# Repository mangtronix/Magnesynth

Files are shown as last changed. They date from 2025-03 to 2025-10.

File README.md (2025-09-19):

# Magnesynth

Modular synthesizer combining physical strings, modular synthesis, physical computing, and electromagnetic phenomena

A full system is
- CB-100 Center Bridge with handle
- 2x EB-100 End Bridge
- 4x F-100 Foot
- 1x P-100 Pickup Mount
- 1x P-101 Pickup Tone Control
- 1x SH-100 Shelf (Left/Right/Middle)
- 1x TB-100 Tuner Block and nut

Rail parts
- 3x 3030 70cm - [Amazon AE](https://www.amazon.ae/dp/B0CGZVSVVL)
- 2x 3030 30cm - [Amazon AE](https://www.amazon.ae/dp/B0CGZV8VY2)
- 8x 3030 T-slot L corner bracket - [Amazon AE](https://www.amazon.ae/dp/B0CHFF6B6S)
- 1x 3030 inside corner bracket - for holding strings - [Amazon AE](https://www.amazon.ae/dp/B0BFW3GV5R)
  - Cut slots using TOOL-100 String holder cut guide
- M6 hammer bolts w/hex nut - for panels
- M5 round head bolts with M5 nut - 8mm for shelves, 12mm for tuner block - [Amazon AE](https://www.amazon.ae/dp/B0CHMN8DZ2)

Michael_Ang-Magnesynth
[Mang](https://michaelang.com) performing on the Magnesynth

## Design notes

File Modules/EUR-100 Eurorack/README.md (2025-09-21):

# EUR-100 Eurorack

EUR-100 Case Bottom

3D-printed Eurorack case with metal rails. The design is parametric for easy scaling.

The case is designed for internal brackets but could easily be adapted to use bolts that go through the sides of the case. Prints in one piece without supports. The threads for the bolts are printed into the case.

Parts:
- [TipTop Z-rails](https://tiptopaudio.com/z-rails/)
- [TipTop Z-rails brackets](https://tiptopaudio.com/z-rails-brackets/)

Example setup with instrument input, effects, and line level output.



Magnesynth v1 40hp clean

[Magnesynth v1 40hp Modulargrid Rack](https://modulargrid.net/e/racks/view/2945002)

EUR-100 Performance
Live performance in Dubai by Mang

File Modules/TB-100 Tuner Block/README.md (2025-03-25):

# TB-100 Tuner Block

**These parts needs to be strong!** The tuner block and nut hold the tension from the strings.  Use at your own risk.

I recommend printing these parts in **PETG** (ASA/ABS would also likely work).

**I do NOT recommend printing these parts in PLA**.  PLA is likely to fail catastrophically (crack) over time.  

With the Guyker tuning machines listed below the tab on the tuners keeps them from rotating against the block. Otherwise you can use the screws provided with the tuners to keep the tuners from rotating.

Recommended settings:
  - Material: PETG
  - Layers and perimeters
    - Perimeters: 7
    - Solid layers: Top: 6, Bottom: 6
  - Infill
    - Fill density: 40%
    - Fill pattern: Cubic

Parts required:
  - 4x tuning machines, e.g. [1 Set GUYKER Locking Guitar Machine Heads 6R](https://www.aliexpress.com/item/1005008338893519.html)
  - 5x M5 nut
  - 5x M5 round head bolt 12mm

Dimensions of Guyker locking tuner used in reference design
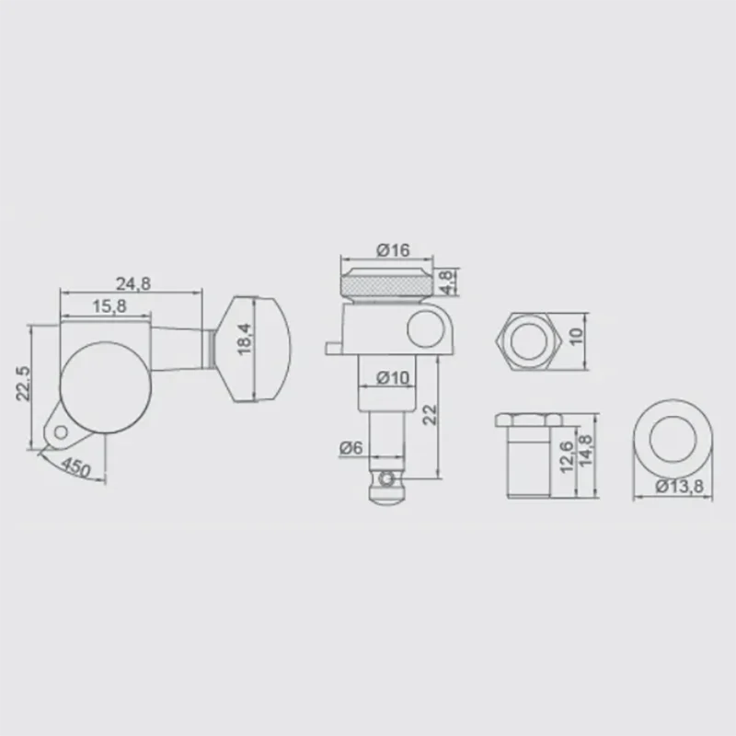
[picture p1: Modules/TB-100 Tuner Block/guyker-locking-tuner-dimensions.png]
Dimensions of Guyker locking tuner


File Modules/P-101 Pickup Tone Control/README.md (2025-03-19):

# P-101 Pickup Tone Control

Parts required
- 250k audio taper potentiometer - Volume control
- 500k audio taper potentiometer - Tone control
- 0.047uF capacitor - Tone control
- 1/4" mono audio jack

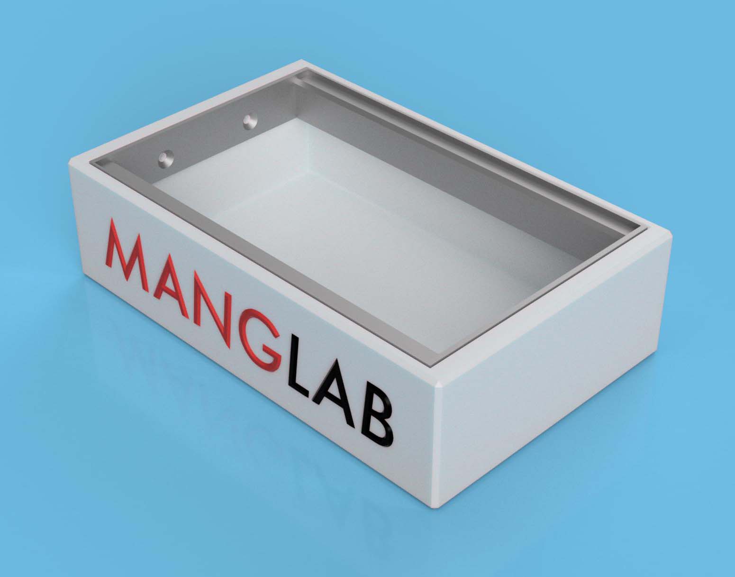
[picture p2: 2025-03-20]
Modules/EUR-100 Eurorack/EUR-100 Case Bottom.jpg

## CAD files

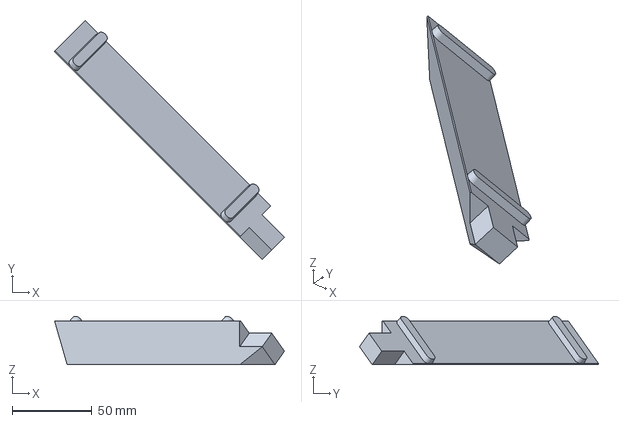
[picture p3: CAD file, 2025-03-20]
Modules/CB-100 Center Bridge with handle/CB-100 CenterBridge-handle-MK4.3mf
144.6 x 150.3 x 30.4 mm

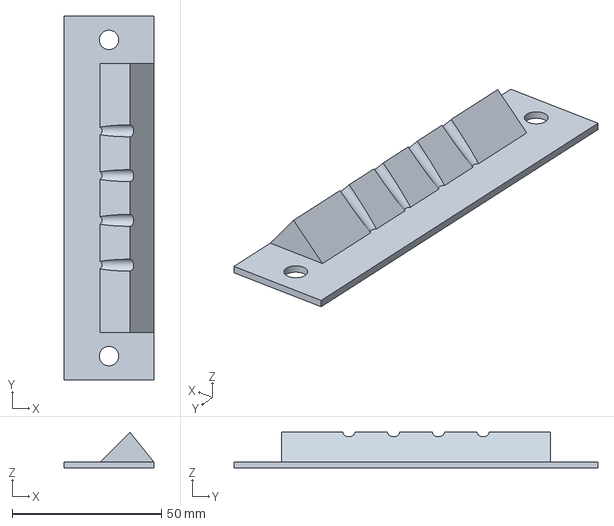
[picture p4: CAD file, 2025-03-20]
Modules/EB-100 End Bridge/B-100 End Bridge - 4mm slots-MK4.3mf
30.0 x 122.0 x 12.0 mm

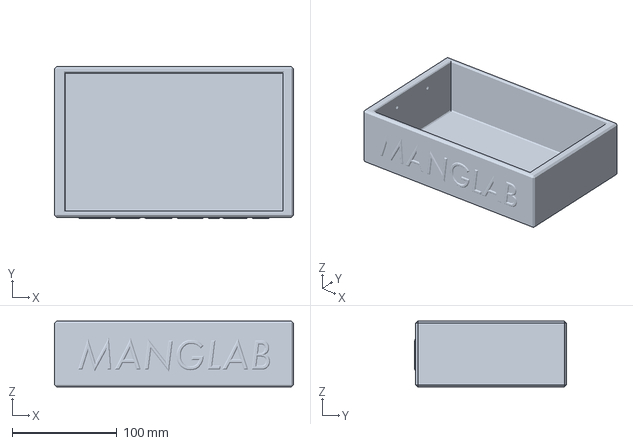
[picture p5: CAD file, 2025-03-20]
Modules/EUR-100 Eurorack/EUR-100 CaseBottom - XL-3T.3mf
228.3 x 145.0 x 63.0 mm

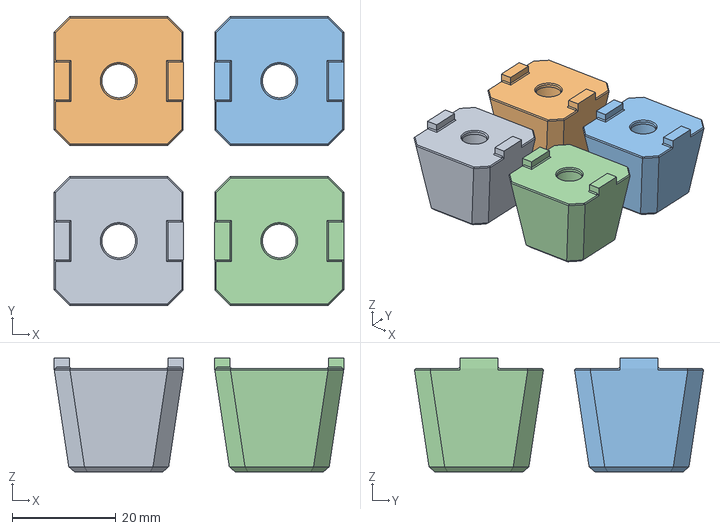
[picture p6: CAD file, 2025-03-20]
Modules/F-100 Foot/F-100 Foot_x4-MK4.3mf
56.0 x 55.8 x 22.0 mm

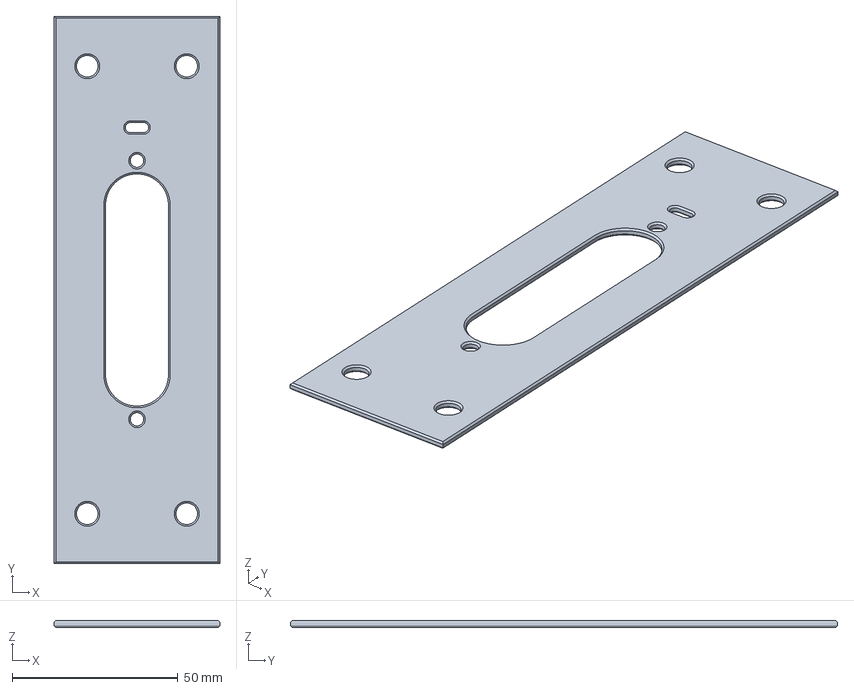
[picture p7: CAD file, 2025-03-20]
Modules/P-100 Pickup Mount/P-100 Pickup Mount-MK4.3mf
50.0 x 165.0 x 2.00 mm

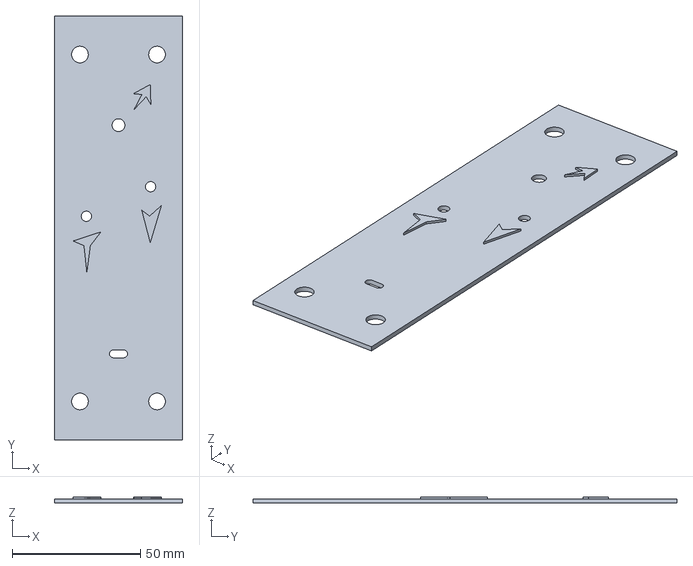
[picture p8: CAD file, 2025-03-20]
Modules/P-101 Pickup Tone Control/P-101 Pickup Tone Control-MK4.3mf
50.0 x 165.0 x 2.40 mm

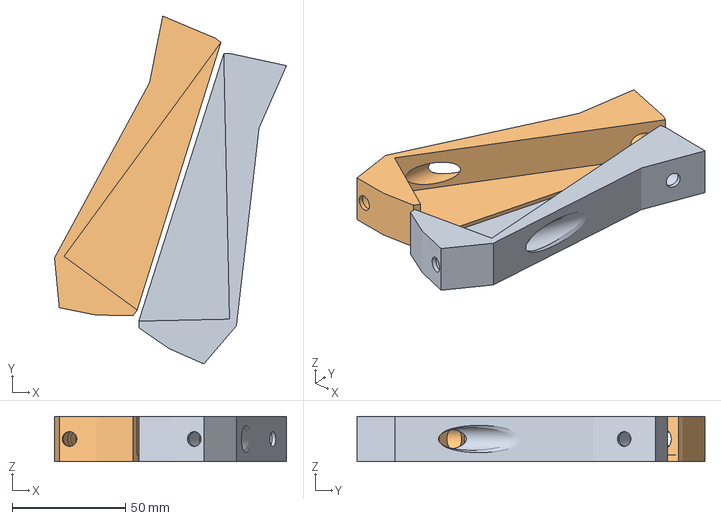
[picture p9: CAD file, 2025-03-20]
Modules/SH-100 Shelf/SH-100 Shelf LR-MK4.3mf
102.3 x 153.3 x 20.0 mm
ShelfL.stl
ShelfR.stl

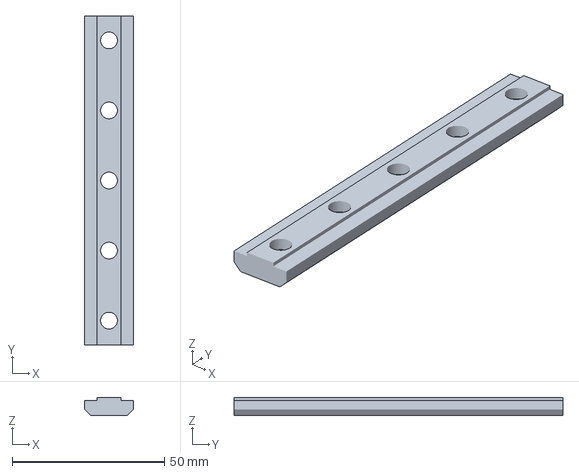
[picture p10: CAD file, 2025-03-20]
Modules/TB-100 Tuner Block/TB-100 Tuner BlockNut-MK4.3mf
16.0 x 108.0 x 6.00 mm

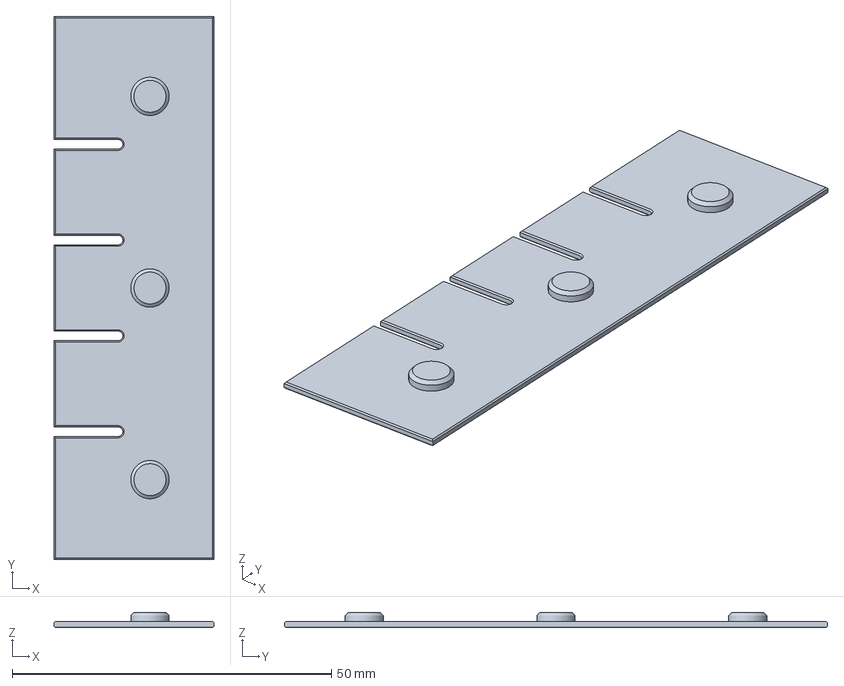
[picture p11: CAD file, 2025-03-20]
Modules/TOOL-100 String holder cut guide/TOOL-100 String holder cut guide-MK4.3mf
25.0 x 85.0 x 2.40 mm

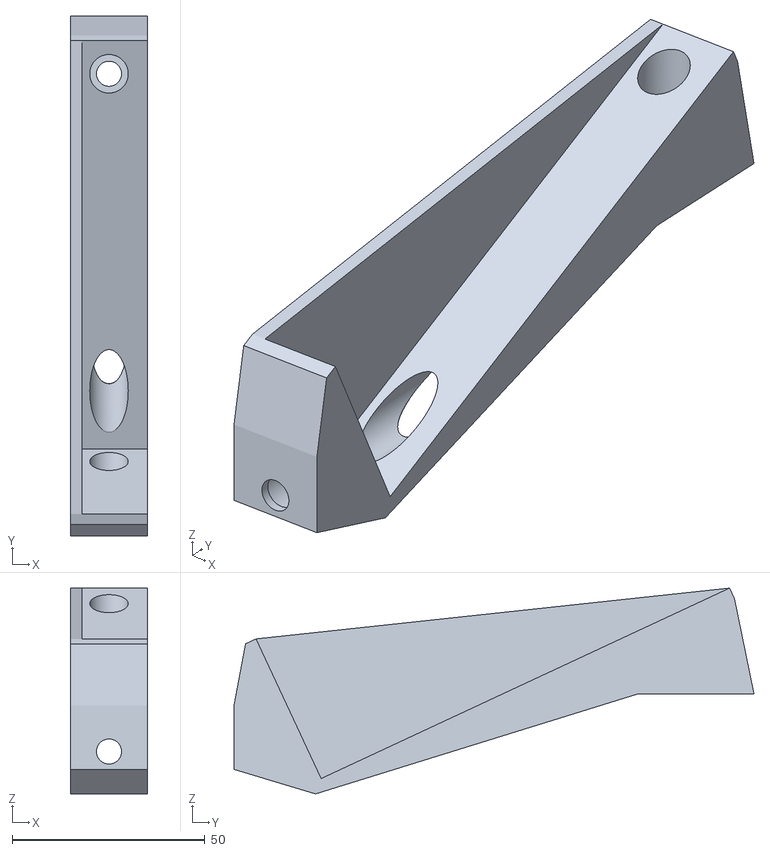
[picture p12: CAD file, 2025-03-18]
Versions/v89/String Thing v89_String Thing v89_ShelfL_1_ShelfL.stl
20.0 x 135.0 x 53.4

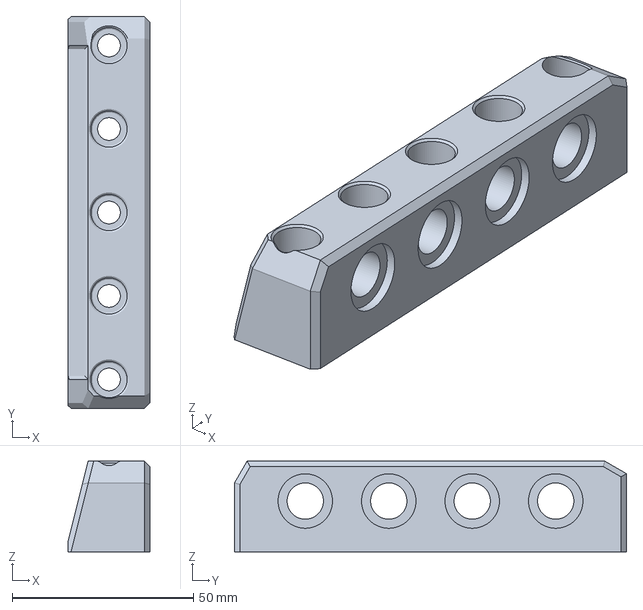
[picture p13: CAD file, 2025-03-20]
Modules/TB-100 Tuner Block/TB-100 Tuner Block-MK4.3mf
22.5 x 108.0 x 25.0 mm

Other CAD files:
Modules/CB-100 Center Bridge with handle/CB-100 CenterBridge-handle-Mini.3mf
Modules/EB-100 End Bridge/B-100 End Bridge - 4mm slots-MK3S.3mf
Modules/F-100 Foot/F-100 Foot_x4-Mini.3mf
Modules/P-100 Pickup Mount/P-100 Pickup Mount-MK3.3mf
Modules/P-101 Pickup Tone Control/P-101 Pickup Tone Control-MK3S.3mf
Modules/SH-100 Shelf/SH-100 Shelf LR-MK3S.3mf
Modules/TOOL-100 String holder cut guide/TOOL-100 String holder cut guide-MK3S.3mf
Modules/CB-100 Center Bridge with handle/CB-100 CenterBridge with handle.stl
Modules/EB-100 End Bridge/B-100 End Bridge - 4mm slots.stl
Modules/EUR-100 Eurorack/EUR-100 Eurorack.f3d
Modules/F-100 Foot/F-100 Foot.stl
Modules/P-100 Pickup Mount/P-100 Pickup Mount.stl
Modules/P-101 Pickup Tone Control/P-101 Pickup Tone Control.stl
Modules/SH-100 Shelf/SH-100-L Shelf L.stl
Modules/SH-100 Shelf/SH-100-M Shelf Middle.stl
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

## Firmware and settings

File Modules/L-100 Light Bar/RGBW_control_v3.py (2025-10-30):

# SPDX-FileCopyrightText: 2021 Kattni Rembor for Adafruit Industries
# SPDX-License-Identifier: MIT

# CREATED BY: Mustafa Bakir
#             Using Claude 4.5
# DATE      : 09/10/2025
# ---------MANGLAB----------
"""
NeoPixel RGBW Control using NeoKey and NeoSlider with Preset Storage
- Button A controls Red channel
- Button B controls Green channel
- Button C controls Blue channel
- Button D controls White/Brightness/Alpha channel
- Slider adjusts the selected channel(s) value (0-255)
- Multiple channels can be selected simultaneously
- Press a selected button again to deselect it
- Last preset is automatically saved and restored on power-up
"""

import board
import time
import neopixel as board_neopixel
from adafruit_seesaw.seesaw import Seesaw
from adafruit_seesaw.analoginput import AnalogInput
from adafruit_seesaw import neopixel
from adafruit_neokey.neokey1x4 import NeoKey1x4
import microcontroller

# flip display so buttons on right
display = board.DISPLAY
display.rotation = 180

print("NeoPixel RGBW Control Demo - Multi-Channel with Preset Storage")

# debug flags
ENABLE_DEBUG = True
SHOW_CHANNEL_CHANGES = True
SHOW_VALUE_CHANGES = True

# preset storage config
PRESET_SAVE_DELAY = 2.0  # secs before auto-save
MAGIC_BYTE = 0xA5  # magic byte for valid data
NVM_START_ADDR = 0  # start addr in nvm

# let i2c devices wake up
time.sleep(0.5)

# neopixel strip on A0 (8px)
NUM_PIXELS = 8
main_pixels = board_neopixel.NeoPixel(board.A0, NUM_PIXELS, brightness=1.0, auto_write=False, pixel_order=board_neopixel.GRBW)

# neoslider setup
i2c = board.I2C()
neoslider_address = 0x38  # A3 cut to avoid conflict w/ neokey at 0x30
print("Connecting to NeoSlider at %x" % neoslider_address)
neoslider = Seesaw(i2c, neoslider_address)
fader = AnalogInput(neoslider, 18)  # slider position
slider_pixels = neopixel.NeoPixel(neoslider, 14, 4, pixel_order=neopixel.GRB)

# neokey setup
print("Setting up NeoKey")
neokey = NeoKey1x4(i2c, addr=0x30)

# preset storage funcs
def save_preset(r, g, b, w):
    """save rgbw to nvm: [magic, r, g, b, w, checksum]"""
    try:
        # calc checksum (xor all vals)
        checksum = MAGIC_BYTE ^ r ^ g ^ b ^ w

        # prep data
        data = bytearray([MAGIC_BYTE, r, g, b, w, checksum])

        print("=== SAVING PRESET ===")
        print(f"Saving: R={r}, G={g}, B={b}, W={w}")
        print(f"Data to write: {[hex(b) for b in data]}")

        # write to nvm
        microcontroller.nvm[NVM_START_ADDR:NVM_START_ADDR + 6] = data

        # verify write
        verify = microcontroller.nvm[NVM_START_ADDR:NVM_START_ADDR + 6]
        print(f"Verification read: {[hex(b) for b in verify]}")

        if list(data) == list(verify):
            print("✓ Preset saved and verified successfully")
            print("=== END SAVE ===\n")
            return True
        else:
            print("ERROR: Write verification failed!")
            print("=== END SAVE ===\n")
            return False

    except Exception as e:
        print(f"ERROR saving preset: {e}")
        import traceback
        traceback.print_exception(e)
        return False

def load_preset():
    """load rgbw from nvm, returns (r,g,b,w) or None"""
    try:
        # read 6 bytes
        data = microcontroller.nvm[NVM_START_ADDR:NVM_START_ADDR + 6]

        # debug: show raw mem
        print("=== NVM DEBUG ===")
        print(f"Raw NVM bytes: {[hex(b) for b in data]}")
        print(f"Magic byte expected: {hex(MAGIC_BYTE)}, found: {hex(data[0])}")

        # verify magic byte
        if data[0] != MAGIC_BYTE:
            print("No valid preset found (magic byte mismatch)")
            print(f"This is likely first boot or memory was cleared")
            return None

        # extract vals
        r, g, b, w = data[1], data[2], data[3], data[4]
        stored_checksum = data[5]

        print(f"Stored values: R={r}, G={g}, B={b}, W={w}")
        print(f"Stored checksum: {hex(stored_checksum)}")

        # verify checksum
        calculated_checksum = MAGIC_BYTE ^ r ^ g ^ b ^ w
        print(f"Calculated checksum: {hex(calculated_checksum)}")

        if calculated_checksum != stored_checksum:
            print("ERROR: Preset corrupted (checksum mismatch)")
            return None

        # validate ranges (0-255)
        if not all(0 <= val <= 255 for val in [r, g, b, w]):
            print("ERROR: Preset values out of range")
            return None

        print(f"✓ Preset loaded successfully: R={r}, G={g}, B={b}, W={w}")
        print("=== END NVM DEBUG ===\n")
        return (r, g, b, w)

    except Exception as e:
        print(f"ERROR loading preset: {e}")
        import traceback
        traceback.print_exception(e)
        return None

def clear_preset():
    """clear stored preset"""
    try:
        microcontroller.nvm[NVM_START_ADDR:NVM_START_ADDR + 6] = bytearray([0] * 6)
        debug_print("Preset cleared", "general")
    except Exception as e:
        print(f"Error clearing preset: {e}")

# init rgbw - try load from storage first
stored_preset = load_preset()
if stored_preset:
    red_value, green_value, blue_value, white_value = stored_preset
    print(f"Restored preset: R={red_value}, G={green_value}, B={blue_value}, W={white_value}")
else:
    red_value = 0
    green_value = 0
    blue_value = 0
    white_value = 0
    print("Starting with default values (all zeros)")

# track selected channels [r, g, b, w]
selected_channels = [False, False, False, False]

# prev button states for edge detection
prev_button_states = [False, False, False, False]

# prev slider val for change detection
prev_slider_value = -1

# auto-save tracking
last_change_time = time.monotonic()
values_need_saving = False
last_saved_values = (red_value, green_value, blue_value, white_value)

def debug_print(message, debug_type="general"):
    """print debug msgs based on flags"""
    if not ENABLE_DEBUG:
        return

    if debug_type == "channel" and SHOW_CHANNEL_CHANGES:
        print(message)
    elif debug_type == "value" and SHOW_VALUE_CHANGES:
        print(message)
    elif debug_type == "general":
        print(message)

def map_slider_to_byte(value):
    """map slider val (0-1023) to byte (0-255)"""
    return int(value * 255 / 1023)

def update_main_pixels():
    """update all neopixels w/ current rgbw"""
    for i in range(NUM_PIXELS):
        if hasattr(main_pixels, 'fill'):
            main_pixels[i] = (red_value, green_value, blue_value, white_value)
        else:
            # rgb pixels - use white as brightness
            brightness_factor = (white_value / 255.0) if white_value > 0 else 1.0
            main_pixels[i] = (
                int(red_value * brightness_factor),
                int(green_value * brightness_factor),
                int(blue_value * brightness_factor)
            )
    main_pixels.show()

def update_slider_leds():
    """update slider leds to show channel selection"""
    num_selected = sum(selected_channels)

    if num_selected == 0:
        # no channels - dim white
        slider_pixels.fill((10, 10, 10))
    elif num_selected == 1:
        # single channel - show color
        if selected_channels[0]:  # red
            slider_pixels.fill((255, 0, 0))
        elif selected_channels[1]:  # green
            slider_pixels.fill((0, 255, 0))
        elif selected_channels[2]:  # blue
            slider_pixels.fill((0, 0, 255))
        elif selected_channels[3]:  # white
            slider_pixels.fill((255, 255, 255))
    else:
        # multi channel - show mix
        r = 255 if selected_channels[0] else 0
        g = 255 if selected_channels[1] else 0
        b = 255 if selected_channels[2] else 0
        w = 255 if selected_channels[3] else 0

        # blend white in if selected
        if selected_channels[3]:
            r = min(255, r + 128)
            g = min(255, g + 128)
            b = min(255, b + 128)

        slider_pixels.fill((r, g, b))

def get_selected_channels_string():
    """get string repr of selected channels"""
    channel_names = ["R", "G", "B", "W"]
    selected = [channel_names[i] for i, sel in enumerate(selected_channels) if sel]
    return "+".join(selected) if selected else "None"

def check_and_save_preset():
    """check if preset needs saving and save if appropriate"""
    global values_need_saving, last_saved_values

    current_values = (red_value, green_value, blue_value, white_value)

    if values_need_saving and current_values != last_saved_values:
        current_time = time.monotonic()

        # save if enough time passed since last change
        if current_time - last_change_time >= PRESET_SAVE_DELAY:
            if save_preset(red_value, green_value, blue_value, white_value):
                last_saved_values = current_values
                values_need_saving = False

# init neokey leds to show current vals
for i in range(4):
    if i == 0:
        neokey.pixels[0] = (red_value//8, 0, 0)
    elif i == 1:
        neokey.pixels[1] = (0, green_value//8, 0)
    elif i == 2:
        neokey.pixels[2] = (0, 0, blue_value//8)
    elif i == 3:
        neokey.pixels[3] = (white_value//8, white_value//8, white_value//8)

# init display w/ restored preset
update_main_pixels()
update_slider_leds()

print("Entering main loop")
print("Press buttons to select/deselect color channels")
print("Multiple channels can be selected simultaneously")
print("Move slider to adjust selected channel(s)")
print(f"Preset will auto-save after {PRESET_SAVE_DELAY}s of inactivity")

while True:
    # neokey handling - check button presses (edge detection)
    for i in range(4):
        current_state = neokey[i]

        # detect button press (rising edge)
        if current_state and not prev_button_states[i]:
            # toggle selection
            selected_channels[i] = not selected_channels[i]

            channel_names = ["Red", "Green", "Blue", "White/Brightness"]

            if selected_channels[i]:
                debug_print(f"Selected {channel_names[i]} channel", "channel")
            else:
                debug_print(f"Deselected {channel_names[i]} channel", "channel")

            debug_print(f"Active channels: {get_selected_channels_string()}", "channel")
            update_slider_leds()

        prev_button_states[i] = current_state

    # update neokey leds to show selection and vals
    for i in range(4):
        if selected_channels[i]:
            # bright color for selected
            if i == 0:
                neokey.pixels[0] = (255, 0, 0)
            elif i == 1:
                neokey.pixels[1] = (0, 255, 0)
            elif i == 2:
                neokey.pixels[2] = (0, 0, 255)
            elif i == 3:
                neokey.pixels[3] = (255, 255, 255)
        else:
            # dim indicator showing current val
            if i == 0:
                neokey.pixels[0] = (red_value//8, 0, 0)
            elif i == 1:
                neokey.pixels[1] = (0, green_value//8, 0)
            elif i == 2:
                neokey.pixels[2] = (0, 0, blue_value//8)
            elif i == 3:
                neokey.pixels[3] = (white_value//8, white_value//8, white_value//8)

    # neoslider handling - adjust selected channel(s)
    if any(selected_channels):
        current_slider_value = map_slider_to_byte(fader.value)

        # only update if slider val changed
        if current_slider_value != prev_slider_value:
            prev_slider_value = current_slider_value
            values_changed = False
            changed_channels = []

            # update all selected channels
            if selected_channels[0]:  # red
                red_value = current_slider_value
                values_changed = True
                changed_channels.append(f"R:{red_value}")

            if selected_channels[1]:  # green
                green_value = current_slider_value
                values_changed = True
                changed_channels.append(f"G:{green_value}")

            if selected_channels[2]:  # blue
                blue_value = current_slider_value
                values_changed = True
                changed_channels.append(f"B:{blue_value}")

            if selected_channels[3]:  # white/brightness
                white_value = current_slider_value
                values_changed = True
                changed_channels.append(f"W:{white_value}")

            if values_changed:
                update_main_pixels()

                # mark vals need saving and update timestamp
                values_need_saving = True
                last_change_time = time.monotonic()

                if changed_channels:
                    debug_print(f"Updated: {', '.join(changed_channels)}", "value")
                    debug_print(f"Current RGBW: [{red_value}, {green_value}, {blue_value}, {white_value}]", "value")

    # check if we need to auto-save preset
    check_and_save_preset()

    # small delay to prevent overwhelming i2c bus
    time.sleep(0.01)

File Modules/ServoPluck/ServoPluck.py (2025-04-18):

import board
import time
import pwmio
from adafruit_motor import servo
from adafruit_neokey.neokey1x4 import NeoKey1x4
# Flip display so buttons are on right
display = board.DISPLAY
display.rotation = 180

# Set false to skip printing debug messages - faster performance
serial_debug = True

from rainbowio import colorwheel
from adafruit_seesaw.seesaw import Seesaw
from adafruit_seesaw.analoginput import AnalogInput
from adafruit_seesaw import neopixel
from adafruit_neokey.neokey1x4 import NeoKey1x4

pins = [board.D5, board.D6, board.D9, board.D10]

# Give I2C devices a chance to turn on
time.sleep(0.5)

# create a PWMOut object on Pin A2.
pwm = pwmio.PWMOut(pins[0], frequency=100)

# Create a servo object, my_servo.
my_servo = servo.ContinuousServo(pwm)

# variable to toggle between forward and back
forward = True

# control speed with fader
speed = 1.0

## NeoSlider Setup
i2c = board.I2C()  # uses board.SCL and board.SDA
#neoslider = Seesaw(i2c, 0x30) # Default address
neoslider_address = 0x38 # Address with A3 cut, to avoid conflicts with Neokey at 0x30
print("Connecting to Neoslider at %x" % neoslider_address)
neoslider = Seesaw(i2c, neoslider_address) # Object to talk to NeoSlider hardware
fader = AnalogInput(neoslider, 18) # Tracks position of slider
old_fader_value = fader.value # Keep track of old value so we can respond to changes
pixels = neopixel.NeoPixel(neoslider, 14, 4, pixel_order=neopixel.GRB) # For changing colors

## Set up Neokey
print("Setting up NeoKey")
# Create a NeoKey object using existing i2c bus
neokey = NeoKey1x4(i2c, addr=0x30) # Default address


def fader_to_color(value):
    """Scale the fader values (0-1023) to the colorwheel values (0-255)."""
    return value / 1023 * 255

def fader_to_speed(value):
    return value / 1023

print("Entering main loop")
while True:
    ### NeoSlider handling
    new_fader_value = fader.value # Get the current position
    if new_fader_value != old_fader_value:
        # Position has changed
        if serial_debug:
            print(new_fader_value)

        # Fill the pixels a color based on the position of the fader.
        pixels.fill(colorwheel(fader_to_color(new_fader_value)))
        old_fader_value = new_fader_value

    ### NeoKey handling
    # Check each button, if pressed, light up the matching neopixel!
    if neokey[0]:
        if serial_debug:
            print("Button A")
        neokey.pixels[0] = 0xFF0000
        if forward:
            print("forward")
            my_servo.throttle = fader_to_speed(fader.value)
            forward = False
        else:
            print("reverse")
            my_servo.throttle = -1 * fader_to_speed(fader.value)
            forward = True
    else:
        neokey.pixels[0] = 0x0

    if neokey[1]:
        if serial_debug:
            print("Button B")
        neokey.pixels[1] = 0xFFFF00
        my_servo.throttle = 0
        time.sleep(1.0)

    else:
        neokey.pixels[1] = 0x0

    if neokey[2]:
        if serial_debug:
            print("Button C")
        neokey.pixels[2] = 0x00FF00
    else:
        neokey.pixels[2] = 0x0

    if neokey[3]:
        if serial_debug:
            print("Button D")
        neokey.pixels[3] = 0x00FFFF
    else:
        neokey.pixels[3] = 0x0

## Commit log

2025-03-18 First print!
    [String Thing v89_String Thing v89_CenterBridge.stl, String Thing v89_String Thing v89_EndBridge.stl, String Thing v89_String Thing v89_Foot.stl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]
2025-03-18 First version
    [B100 End Bridge - 4mm slots-MK3S.3mf, B100 End Bridge - 4mm slots.stl, CB100 CenterBridge with handle.stl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]
2025-03-19 Rename directories - easier on the eyes
    [B100 End Bridge - 4mm slots-MK3S.3mf, B100 End Bridge - 4mm slots.stl, CB100 CenterBridge with handle.stl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]
2025-03-19 Rename to e.g. F-100. Easier on the eyes
    [B-100 End Bridge - 4mm slots-MK3S.3mf, B-100 End Bridge - 4mm slots.stl, CB-100 CenterBridge with handle.stl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]
2025-03-19 added all the MK4 files
    [B-100 End Bridge - 4mm slots-MK4.3mf, CB-100 CenterBridge-handle-MK4.3mf, F-100 Foot_x4-MK4.3mf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]
2025-03-20 Basic Eurorack case
    [EUR-100 Eurorack.f3d]
2025-03-20 3MF file for tri-colour with Prusa XL
    [EUR-100 CaseBottom - XL-3T.3mf]
2025-03-20 Version 89(!)
    [String Thing v89.f3d]
2025-04-16 code for using a servo to pluck strings - only one servo for now, slider changes how fast it plucks, connect servo to A0
2025-04-18 Servo tester
